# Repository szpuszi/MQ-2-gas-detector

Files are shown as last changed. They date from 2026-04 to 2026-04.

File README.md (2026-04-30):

# MQ-2 Gas Detector V1.0
It's my first custom PCB project created as part of the Hack Club Fallout.
It is designed to detect gas leaks and potential fire hazards.
This project also contains a case.

I made this because I wanted to practice making PCBs and create a practical safety device.
I use it by letting it sit and monitor gas levels in my room to ensure I'm in a safe environment.

## How it works:
The heart of this project is ATmega328P microcontroller. The board is powered via 5V USB-C (Adafruit 4090). The firmware features pre-heating phase (5mins) and a startup test function which lights up the LEDs and beeps the buzzer so you can know if it works correctly. It monitors gas levels in the air using an MQ-2 sensor and indicates safety levels by 3 LEDs and a buzzer:
- 🟢 Air is safe.
- 🟡 Gas levels are elevated. (warning)
- 🔴 High gas levels, it may be unsafe to inhale them.
<small> Thresholds were calibrated based on local home testing, sensitivity can vary depending on environment and gas type. </small>

### Shopping list 🛒: 
<small> BOM is available [here](Manufacturing/BOM.csv) </small>
You will also need:
- basic soldering kit (soldering iron, solder)
- PCB (can order on websites like JLCPCB, files for them are in Manufacturing Files.zip folder)
- Double Sided Tape
- DuPont Male/Female wires
- Glue (for the case, it needs to stick to plastic)
- cutting pliers

Total for everything is ≈ 40USD

### Manufacturing Notes🏭:
<small> All files required for production are included [here](Manufacturing/Manufacturing%20Files.zip) </small>

## 📖 Fallout Zine Page
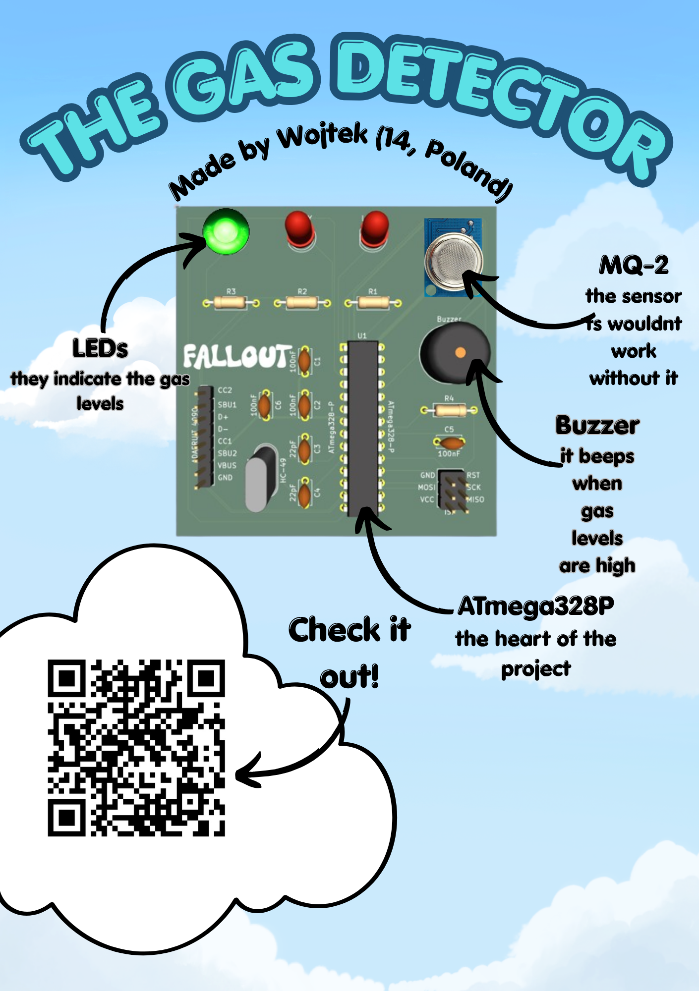
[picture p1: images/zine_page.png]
Zine Page


# Assembly and firmware
Refer to the schematic and PCB layout for assembly. The PCB features a well detailed silkscreen with all components values and identifiers clearly marked to ensure easy and error-free assembly. The firmware is available [here](firmware/gas_detector.ino)
# Gallery📷
**CASE**
obraz
obraz
obraz
**PCB**
obraz
obraz
obraz
obraz
obraz

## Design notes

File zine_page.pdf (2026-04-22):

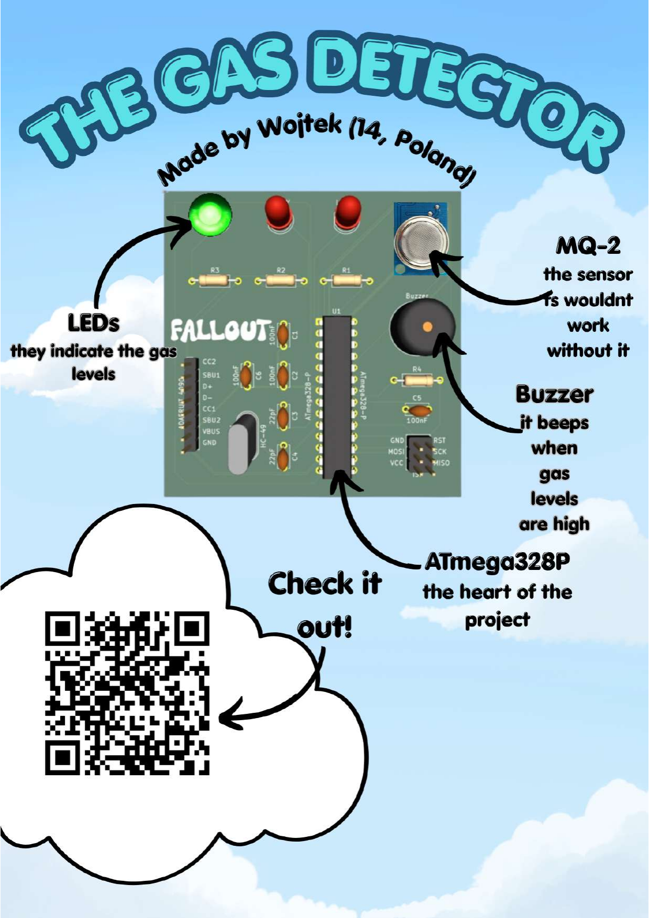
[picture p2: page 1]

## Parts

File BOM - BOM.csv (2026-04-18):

Designator | Value | Quantity | Description | Link
U1 | ATmega328P-P | 1 | Microcontroller (DIP-28 package) | https://www.digikey.com/en/products/detail/microchip-technology/ATMEGA328P-PU/1914589
MQ-2 | MQ-2 | 1 | Gas Sensor Module | https://www.digikey.com/en/products/detail/olimex-ltd/SNS-MQ2/21662532
J2 | Conn_01x08 | 1 | USB Type C Breakout Board - Downstream Connection | https://www.adafruit.com/product/4090
R1-R3 | 220R | 3 | Resistor for LEDs (Through-hole) | https://www.adafruit.com/product/2780
R4 | 10R | 1 | Pull-up Resistor (Through-hole) | https://www.adafruit.com/product/2784
C1,C2,C5,C6 | 100nF | 4 | Ceramic Capacitor (104) | https://www.adafruit.com/product/753
C3,C4 | 22pF | 2 | Ceramic Capacitor for Crystal | https://www.digikey.com/en/products/detail/vishay-beyschlag-draloric-bc-components/K220J15C0GF53L2/2821623
Y1 | 16MHz | 1 | HC-49 Crystal | https://www.adafruit.com/product/2215
D1,D2,D3 | LED_G,LED_Y,LED_R | 1 | G,Y,R LED | https://www.adafruit.com/product/4203
BZ1 | Buzzer | 1 | 12x9.5mm Active Buzzer (RM.7.5) | https://www.amazon.com/dp/B0F1KCZGZG/ref=twister_B0FP83KQTB?_encoding=UTF8&th=1
J1 | ISP | 1 | ISP programming interface | https://www.amazon.com/dp/B08R8LGM4L/ref=twister_B08ZJ5NYY8?_encoding=UTF8&th=1
none | none | 1 | MQ-2 sensor female header | https://www.digikey.com/en/products/detail/samtec-inc/ESQT-104-03-M-S-310/5270322

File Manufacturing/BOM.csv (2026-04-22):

Designator | Value | Quantity | Description | Link
U1 | ATmega328P-P | 1 | Microcontroller (DIP-28) | https://botland.com.pl/avr-w-obudowie-tht/1264-mikrokontroler-avr-atmega328p-u-dip-5903351249928.html
MQ-2 | MQ-2 | 1 | Gas Sensor Module | https://allegro.pl/oferta/czujnik-dymu-i-gazow-latwopalnych-mq-2-modul-detekcji-5v-150ma-50-c-15262241063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
J2 | Conn_01x08 | 1 | USB Type C Breakout Board - Downstream Connection | https://www.adafruit.com/product/4090
R1-R3 | 220R | 3 | Resistor for LEDs | https://botland.com.pl/rezystory-przewlekane/20014-rezystor-justpi-tht-cf-weglowy-14w-220-30szt-5904422329020.html
R4 | 10K | 1 | Pull-up Resistor | https://botland.com.pl/rezystory-przewlekane/20150-rezystor-justpi-tht-cf-weglowy-14w-10k-30szt-5904422329280.html
C1,C2,C5,C6 | 100nF | 4 | Ceramic Capacitor | https://allegro.pl/produkt/kondensator-ceramiczny-100nf-50v-20szt-34571a79-9f0e-4410-b92e-28d50d95ad61?offerId=11813029272
C3,C4 | 22pF | 2 | Ceramic Capacitors for Crystal | https://allegro.pl/produkt/kondensator-ceramiczny-22pf-50v-10szt-raster-5-91fd0173-13ec-4f39-bfed-c8610bd964cb?offerId=13624968332
Y1 | 16MHz | 1 | HC-49 Crystal | https://botland.com.pl/rezonatory/166-rezonator-kwarcowy-16mhz-hc49-niski-10szt-5904422358761.html
D1,D2,D3 | LED_G,LED_Y,LED_R | 1 | G,Y,R LED | https://botland.com.pl/diody-led/19985-zestaw-diod-led-5mm-justpi-30szt-5904422329259.html
BZ1 | Buzzer | 1 | 12x9.5mm Active Buzzer (RM.7.5) | https://allegro.pl/oferta/buzzer-aktywny-z-generatorem-5v-85db-16547323388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
J1 | ISP | 1 | ISP programming interface | https://botland.com.pl/gniazda-szpilkowe-goldpin/5873-gniazdo-zenskie-2x3-raster-254mm-5-szt-5904422374693.html
none | none | 1 | Adafruit 4090 Male Header | https://botland.com.pl/akcesoria-do-raspberry-pi-pico/18854-zestaw-zlacz-meskich-do-gpio-raspberry-pi-pico-5904422328511.html
none | none | 1 | MQ-2 sensor female header | https://botland.com.pl/gniazda-szpilkowe-goldpin/8503-gniazdo-proste-1x4pin-raster-254mm-pionowe-10szt-5904422336554.html
none | none | 1 | Breadboard (for connecting the microcontroller with arduino for programming) | https://botland.com.pl/plytki-stykowe/19943-plytka-stykowa-justpi-830-otworow-5904422328610.html
none | none | 1 | Jumper wires for programming Male/Male | https://botland.com.pl/przewody-polaczeniowe-mesko-meskie/19622-zestaw-przewodow-polaczeniowych-justpi-mesko-meskie-20cm-40szt-5903351243018.html
none | none | 1 | Jumper wires for MQ-2 Male/Female | https://botland.com.pl/przewody-polaczeniowe-zensko-meskie/19949-przewody-polaczeniowe-zensko-meskie-justpi-10cm-40szt-5904422328696.html
none | none | 1 | Arduino Nano or any other arduino (for programming) | https://allegro.pl/oferta/nano-3-0-atmega328-ch340-kompatybilny-z-arduino-usb-c-niezlutowany-16578881126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
TOTAL | ≈ 32.76USD

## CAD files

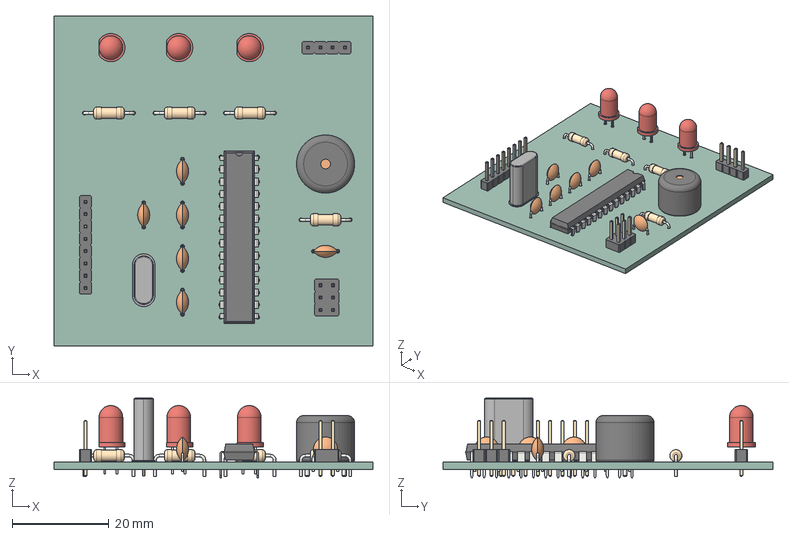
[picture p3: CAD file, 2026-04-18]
.step
65.8 x 68.0 x 16.4 mm
C_Disc_D5.0mm_W2.5mm_P5.00mm x 6
LED_D5.0mm x 3
R_Axial_DIN0207_L6.3mm_D2.5mm_P10.16mm_Horizontal x 4
DIP-28_W7.62mm
PinHeader_1x08_P2.54mm_Vertical
Buzzer_12x9.5RM7.6
PinHeader_2x03_P2.54mm_Vertical
Crystal_HC49-U_Vertical
PinHeader_1x04_P2.54mm_Vertical
gas_detector_PCB

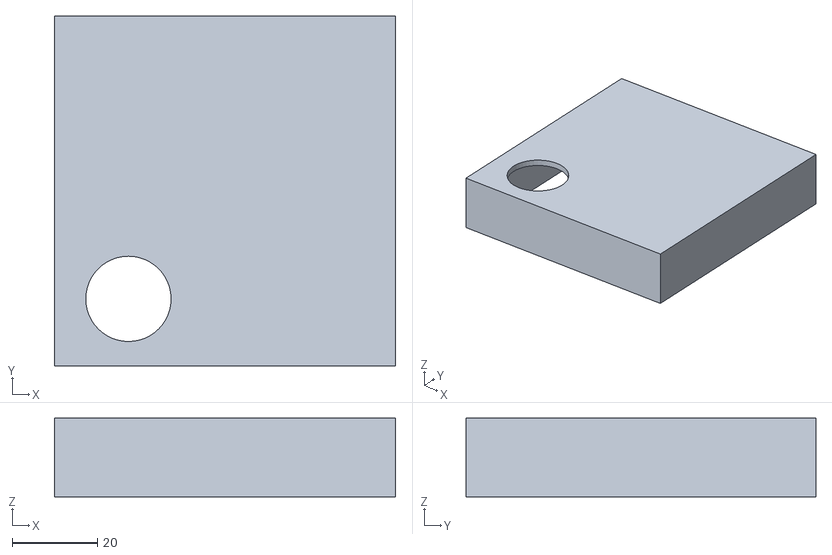
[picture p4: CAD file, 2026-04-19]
3d_models/3d_printing/Gas detector case top.stl
80.0 x 82.0 x 18.5

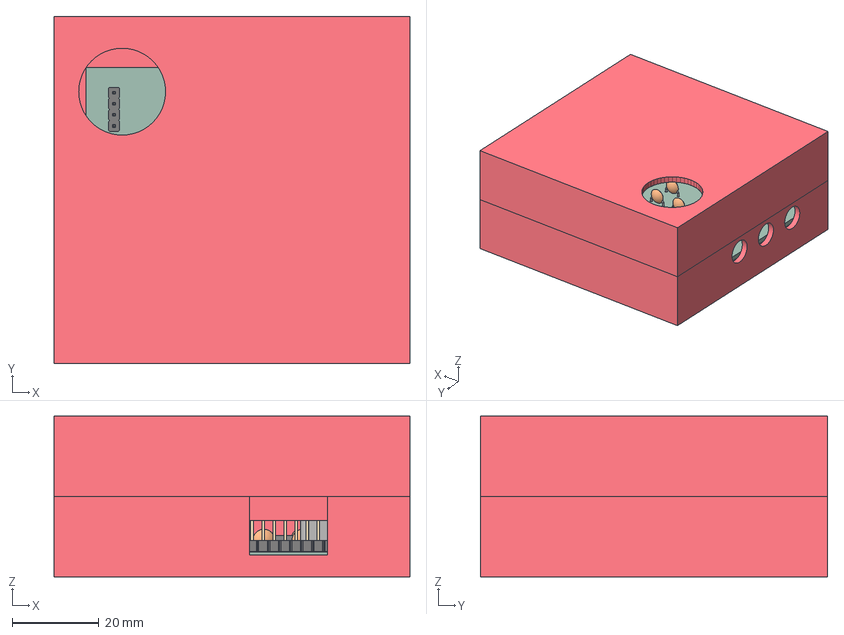
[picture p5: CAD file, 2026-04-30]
3d_models/Gas detector.step
82.0 x 80.0 x 37.0 mm
C_Disc_D5.0mm_W2.5mm_P5.00mm x 6
LED_D5.0mm x 3
R_Axial_DIN0207_L6.3mm_D2.5mm_P10.16mm_Horizontal x 4
DIP-28_W7.62mm
PinHeader_1x08_P2.54mm_Vertical
Buzzer_12x9.5RM7.6
PinHeader_2x03_P2.54mm_Vertical
Crystal_HC49-U_Vertical
PinHeader_1x04_P2.54mm_Vertical
gas_detector_PCB

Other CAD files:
3d_models/3d_printing/Gas detector Case bottom.stl
3d_models/Gas detector.f3d

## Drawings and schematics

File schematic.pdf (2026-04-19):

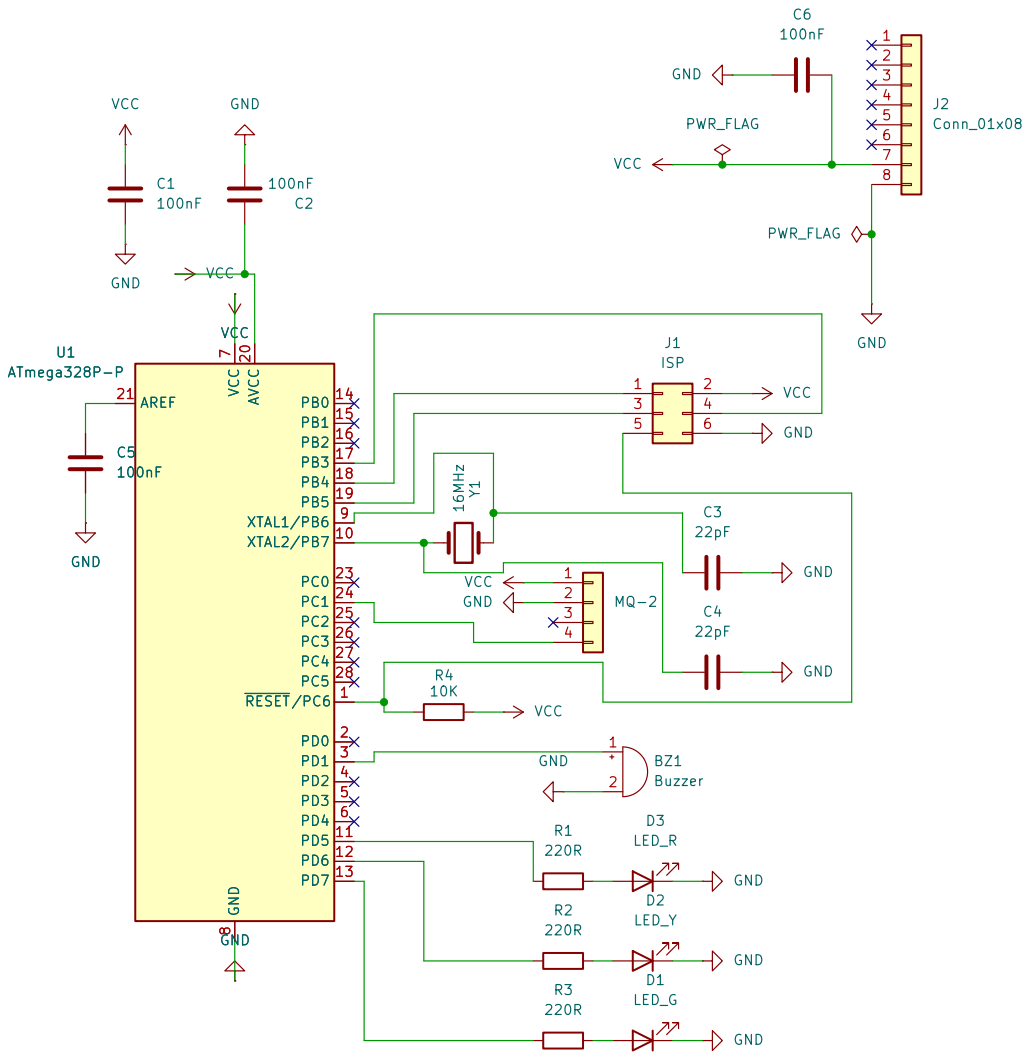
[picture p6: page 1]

Size: A4 | Rev:
KiCad E.D.A. 10.0.1 | Id: 1/1

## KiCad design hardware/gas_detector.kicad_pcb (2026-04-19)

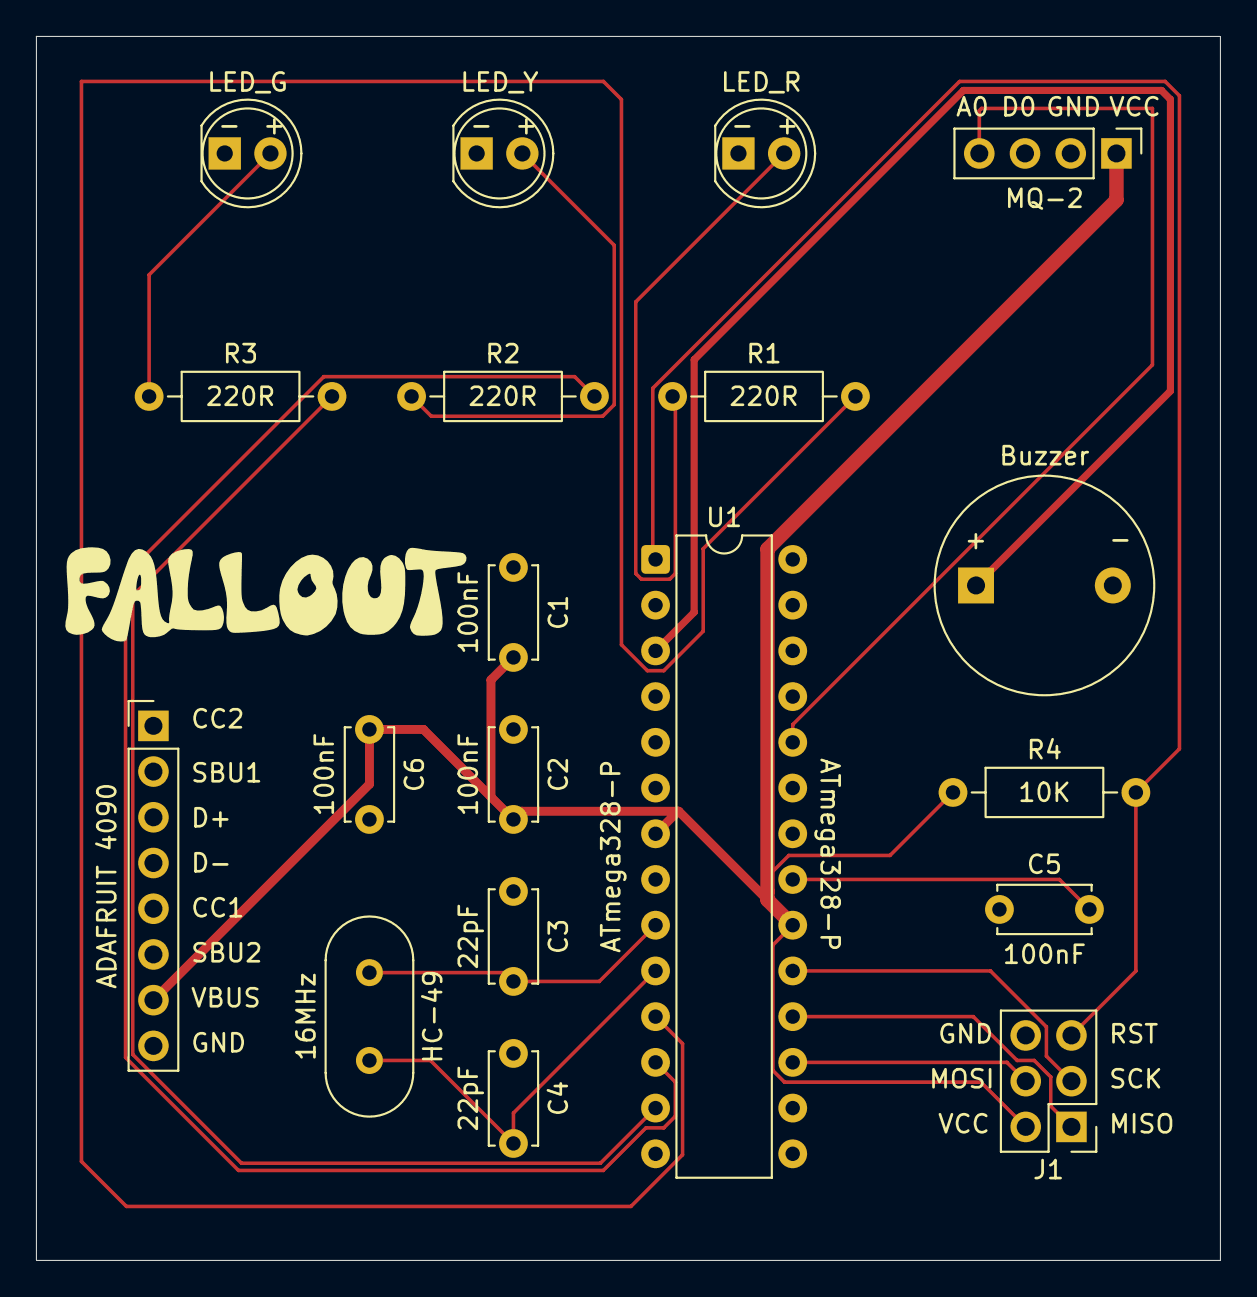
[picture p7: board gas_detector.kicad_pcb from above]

Board: 2 copper layers, 65.8 x 68.0 mm, 19 parts (0 on the bottom side), 17 nets.

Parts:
Buzzer: Buzzer; Buzzer_12x9.5RM7.6
C1, C2, C5, C6: 100nF; C_Disc_D5.0mm_W2.5mm_P5.00mm
C3, C4: 22pF; C_Disc_D5.0mm_W2.5mm_P5.00mm
HC-49: 16MHz; Crystal_HC49-U_Vertical
J1: ISP; PinHeader_2x03_P2.54mm_Vertical
J2: Conn_01x08; PinHeader_1x08_P2.54mm_Vertical
LED_G: LED_G; LED_D5.0mm
LED_R: LED_R; LED_D5.0mm
LED_Y: LED_Y; LED_D5.0mm
MQ-2: MQ-2; PinHeader_1x04_P2.54mm_Vertical
R1, R2, R3: 220R; R_Axial_DIN0207_L6.3mm_D2.5mm_P10.16mm_Horizontal
R4: 10K; R_Axial_DIN0207_L6.3mm_D2.5mm_P10.16mm_Horizontal
U1: ATmega328P-P; DIP-28_W7.62mm

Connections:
GND: Buzzer.2 (-), C1.1, C2.1, C3.1, C4.1, C5.1, C6.1, J1.6 (GND), J2.8 (GND), LED_G.1 (K), LED_R.1 (K), LED_Y.1 (K), MQ-2.2 (GND), U1.8 (GND), U1.22 (GND)
unnamed: Buzzer.1 (+), U1.3 (PD1)
unnamed: LED_G.2 (A), R3.1
unnamed: LED_Y.2 (A), R2.1
unnamed: LED_R.2 (A), R1.1
unnamed: J1.1 (MISO), U1.18 (PB4)
unnamed: J1.4 (MOSI), U1.17 (PB3)
unnamed: J1.5 (RST), R4.2, U1.1 (~RESET/PC6)
unnamed: J1.3 (SCK), U1.19 (PB5)
unnamed: MQ-2.4 (A0), U1.24 (PC1)
unnamed: C5.2, U1.21 (AREF)
unnamed: R1.2, U1.11 (PD5)
unnamed: R2.2, U1.12 (PD6)
unnamed: R3.2, U1.13 (PD7)
unnamed: C3.2, HC-49.1, U1.9 (XTAL1/PB6)
unnamed: C4.2, HC-49.2, U1.10 (XTAL2/PB7)
VCC: C1.2, C2.2, C6.2, J1.2 (VCC), J2.7 (VBUS), MQ-2.1 (VCC), R4.1, U1.7 (VCC), U1.20 (AVCC)

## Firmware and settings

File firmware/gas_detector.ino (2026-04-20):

  int sensorPin = A1;

  int yellowLed = 6;
  int greenLed = 7;
  int redLed = 8;
  int buzzer = 9;

  int baseline = 110;  // test in your environment
  int threshold = baseline + 80;  // test in your environment

  void setup() {
    Serial.begin(9600);

    pinMode(yellowLed, OUTPUT); 
    pinMode(greenLed, OUTPUT);
    pinMode(redLed, OUTPUT);
    pinMode(buzzer, OUTPUT);

    Serial.println("TEST");
    digitalWrite(greenLed, HIGH);
    digitalWrite(yellowLed, HIGH);
    digitalWrite(redLed, HIGH);
    digitalWrite(buzzer, HIGH);

    delay(100);

    digitalWrite(greenLed, LOW);
    digitalWrite(yellowLed, LOW);
    digitalWrite(redLed, LOW);
    digitalWrite(buzzer, LOW);

    delay(1000);

    Serial.println("Heating (5 mins left)");
    for(int i=0; i<300; i++) { digitalWrite(yellowLed, ! digitalRead(yellowLed)); delay(1000); }

    Serial.println("READY");

  }

  void loop() {
    int value = analogRead(sensorPin);

    Serial.print("MQ-2: ");
    Serial.println(value);

    if (value > threshold) {
      // 🔴
      digitalWrite(redLed, HIGH);
      digitalWrite(yellowLed, LOW);
      digitalWrite(greenLed, LOW);
      digitalWrite(buzzer, HIGH);
  }

      else if (value > baseline + 30) {   // test in your environment
      // 🟡 
      digitalWrite(redLed, LOW);
      digitalWrite(yellowLed, HIGH);
      digitalWrite(greenLed, LOW);
      digitalWrite(buzzer, LOW);

    } else {
      // 🟢
      digitalWrite(redLed, LOW);
      digitalWrite(yellowLed, LOW);
      digitalWrite(greenLed, HIGH);
      digitalWrite(buzzer, LOW);
    }

    delay(200);
  }

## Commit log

2026-04-18 Add KiCad files and Manufacturing Files
    [gas_detector.kicad_pcb, gas_detector.kicad_sch]
2026-04-18 Add BOM
    [BOM - BOM.csv]
2026-04-18 Rename BOM - BOM.csv to BOM.csv
    [BOM.csv]
2026-04-18 Fix formatting and descriptions in BOM.csv
    Updated BOM.csv to correct formatting and descriptions.
    [BOM.csv]
2026-04-18 Revise BOM.csv with updated components
    Updated BOM.csv to include new components and correct existing entries.
    [BOM.csv]
2026-04-18 Add STEP file
    [.step]
2026-04-19 Rename gas_detector.kicad_pcb to kicad files/gas_detector.kicad_pcb
    [gas_detector.kicad_pcb]
2026-04-19 Rename gas_detector.kicad_prl to kicad files/gas_detector.kicad_prl
2026-04-19 Rename gas_detector.kicad_pro to kicad files/gas_detector.kicad_pro
2026-04-19 Rename gas_detector.kicad_sch to kicad filesgas_detector.kicad_sch
    [kicad filesgas_detector.kicad_sch]
2026-04-19 Rename kicad filesgas_detector.kicad_sch to kicad files/gas_detector.kicad_sch
    [gas_detector.kicad_sch]
2026-04-19 Rename .step to gas detector.step
    [gas detector.step]
2026-04-19 Update links in README for BOM and manufacturing files
2026-04-19 Rename gas detector.step to gas_detector.step
    [gas_detector.step]
2026-04-19 Update baseline and setup sequence in gas_detector
    Adjusted baseline value and modified setup sequence for LEDs and buzzer.
    [gas_detector.ino]
2026-04-19 Add double sided tape to materials list
2026-04-19 Rename Gas detector Case bottom.stl to 3d_models/Gas detector Case bottom.stl
    [Gas detector Case bottom.stl]
2026-04-19 Rename Gas detector case top.stl to 3d_models/Gas detector case top.stl
    [Gas detector case top.stl]
2026-04-19 Add pcb.step file
    [pcb.step]
2026-04-19 Rename 3d_models/Gas detector Case bottom.stl to 3d_models/case/Gas detector Case bottom.stl
    [Gas detector Case bottom.stl]
2026-04-19 Rename 3d_models/Gas detector case top.stl to 3d_models/case/Gas detector case top.stl
    [Gas detector case top.stl]
2026-04-20 Update glue description in README
    Clarified glue description for case assembly.
2026-04-22 Update BOM.csv with new components and links
    [BOM.csv]
2026-04-22 Add wire cutters to materials list
2026-04-26 Enhance case link with additional URLs
    Updated links for the project case in the README.
2026-04-30 Rename Gas detector case top.stl to Gas detector.stl
    [Gas detector.stl]
2026-04-30 Rename Gas detector Case bottom.stl to Gas detector Case bottom.stl
    [Gas detector Case bottom.stl]
2026-04-30 Rename Gas detector case top.stl to Gas detector case top.stl
    [Gas detector case top.stl]
